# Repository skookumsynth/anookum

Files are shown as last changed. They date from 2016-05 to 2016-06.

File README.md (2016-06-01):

# Anookum

The Anookum is a derivative of Olivier Gillet's "Anushri" monophonic synthesizer.

https://github.com/pichenettes/anushri

It uses alternate parts to make sourcing easier for users in North America.
Files are licensed as per the original CC-BY-SA 3.0 license.

No warranties provided.
www.skookumsynth.com

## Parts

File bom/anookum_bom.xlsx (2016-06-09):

THIS BOM IS BASED ON THE ORIGINAL PROVIDED BY MUTABLE INSTRUMENTS. IT HAS BEEN MODIFIED. WHILE BEST EFFORTS HAVE BEEN MADE, COMPLETE ACCURACY CAN NOT BE GUARANTEED. IF ERRORS ARE NOTED, PLEASE NOTIFY CREATOR
DESIGNATOR | DESCRIPTION | QTY | DIGI-KEY | MOUSER | OTHER (CAVEAT EMPTOR)
RESISTORS
R1, R3, R4, R13 | 220 OHM 1/4W 1% | 4 | RNF14FTD221RCT-ND | 660-MF1/4DCT52R2200F | TAYDA | A-2246
R5, R6, R9, R10, R21, R22, R27, R51, R55, R57, R62 | 470 OHM 1/4W 1% | 11 | RNF14FTD470RCT-ND | 660-MF1/4DCT52R4700F | TAYDA | A-2247
R25, R38, R39, R45, R50, R52, R53 | 4K7 OHM 1/4W 1% | 7 | RNF14FTD4K75CT-ND | 660-MF1/4DCT52R4701F | TAYDA | A-2310
R2, R29, R37, R49, R63, R64, R70, R73, R77 | 10K OHM 1/4W 1% | 9 | RNF14FTD10K0CT-ND | 660-MF1/4DCT52R1002F | TAYDA | A-2203
R28 | 12K OHM 1/4W 1% | 1 | RNF14FTD12K1CT-ND | 660-MF1/4DCT52R1202F | TAYDA | A-2327
R18, R30, R35 | 15K OHM 1/4W 1% | 3 | RNF14FTD15K0CT-ND | 660-MF1/4DCT52R1502F | TAYDA | A-2182
R11, R14, R23, R26, R36, R40, R43, R44, R46, R47 | 22K OHM 1/4W 1% | 10 | RNF14FTD22K1CT-ND | 660-MF1/4DCT52R2202F | TAYDA | A-2284
R72 | 27K OHM 1/4W 1% | 1 | RNF14FTD27K4CT-ND | 660-MF1/4DCT52R2702F | TAYDA | A-2772
R12, R16, R17, R19, R20, R24, R31, R54, R67 | 33K OHM 1/4W 1% | 9 | RNF14FTD33K2CT-ND | 660-MF1/4DCT52R3302F | TAYDA | A-2290
R71 | 39K OHM 1/4W 1% | 1 | RNF14FTD39K2CT-ND | 660-MF1/4DCT52R3902F | TAYDA | A-2313
R68 | 49K9 OHM 1/4W 1% | 1 | RNF14FTD49K9CT-ND | 660-MF1/4DCT52R4992F | TAYDA
R66 | 62K OHM 1/4W 1% | 1 | RNF14FTD61K9CT-ND | 660-MF1/4DCT52R6192F | TAYDA | A-2628
R56, R59 | 68K OHM 1/4W 1% | 2 | RNF14FTD68K1CT-ND | 660-MF1/4DCT52R6812F | TAYDA | A-2334
R7, R8, R33, R34, R41, R42, R48, R60, R61 | 100K OHM 1/4W 1% | 9 | RNF14FTD100KCT-ND | 660-MF1/4DCT52R1003F | TAYDA | A-2248
R32 | 150K OHM 1/4W 1% | 1 | RNF14FTD150KCT-ND | 660-MF1/4DCT52R1503F | TAYDA | A-2210
R15, R58, R65, R69 | 200K OHM 1/4W 1% | 4 | RNF14FTD200KCT-ND | 660-MF1/4DCT52R2003F | TAYDA | A-2630
RN1 | ARRAY 6 RES 10K | 1 | 4607X-101-103LF-ND | 652-4607X-1LF-10K
R74, R75, R76 | TRIMMER 10K | 3 | 490-2875-ND | 652-3296W-1-103LF | TAYDA | A-586
RESISTORS - CONTROL BOARD
R6, R7, R13, R14, R15, R16 | 220 OHM 1/4W 1% | 6 | RNF14FTD221RCT-ND | 660-MF1/4DCT52R2200F | TAYDA | A-2246
CAPACITORS
C20, C51 | CER 10PF 50V NP0 RADIAL | 2 | BC1001CT-ND | 594-K100K15C0GF53L2
C54, C55 | CER 18PF 50V NP0 RADIAL | 2 | BC1004CT-ND | 594-K180J15C0GF5TL2
C12 | CER 100PF 50V NP0 RADIAL | 1 | BC1013CT-ND | 594-K101J15C0GF5TL2
C14, C28 | CER 220PF 50V NP0 RADIAL | 2 | BC1017CT-ND | 23PS122
C8, C17, C30, C32, C35 | CER 560PF 50V NP0 RADIAL | 5 | BC1022CT-ND | 594-K561J15C0GF5TL2
C9 | FILM 2.2N% 63VDC | 1 | 399-9692-1-ND | 23PS222 | TAYDA
C4 | FILM 22N 5% 63VDC | 1 | 399-5451-1-ND | 505-MKS2.022/63/5T | TAYDA
C1, C3, C10, C11, C13, C15, C16, C18, C19, C21, C22, C23, C24, C25, C26, C27, C29, C31, C33, C34, C36, C37, C39, C40, C41, C42, C43, C45, C46, C47, C48, C50, C53 | CER 0.1UF 25V Y5V RADIAL | 33 | BC1148CT-ND | 75-1C10Z5U104M050B | TAYDA | A-214
C2, C5, C6, C7 | ALUM 4.7UF 20% 35V RADIAL | 4 | 493-10854-1-ND | 647-UVP1E4R7MDD
C56 | TANT 10UF 25V 20% | 1 | 478-5813-ND | 581-TAP106K016SRW |  |  | NOT NEEDED IF USED W/ EURORACK PSU
C38, C44, C49, C52, C57 | ALUM 100UF 20% 25V RADIAL | 5 | P10269-ND | 140-SEA101M1CBK0607
SEMICONDUCTORS
D1, D5, D6 | DIODE, GP | 3 | 1N4148TACT-ND | 78-1N4148-TAP | TAYDA | A-157
D3, D4 | DIODE ZENER 3.6V 500MW | 2 | 1N5227B-ND | 512-1N5227B | TAYDA | A-165
D2, D7, D8 | DIODE GEN PURP 50V 1A | 3 | 641-1310-1-ND | 625-1N4001-E3/73 | TAYDA | A-162
Q1 | JFET N-CH 35V 625MW | 1 | J112_D26ZCT-ND | 610-2N5485 | TAYDA | A-908
Q2 | TRANS PNP 40V 0.2A | 1 | 2N3906-APCT-ND | 512-2N3906TA | TAYDA | A-117
Q3 | XTAL 20.0000MHZ 30PPM 20PF | 1 | 631-1111-ND | 717-9B-20.000MAAJ-B | TAYDA | A-236
INTEGRATED CIRCUITS
OK1 | OPTOISO 5KV OPEN COLLECTOR | 1 | 160-1791-ND | 782-6N137 | TAYDA | A-871
IC24 | REG SWTCHD CAP INV RATIO | 1 | 296-17596-5-ND | 595-LT1054CP | FUTURLEC |  | NOT NEEDED IF USED W/ EURORACK PSU
IC23 | MCU 8BIT 32KB FLASH | 1 | ATMEGA328P-PU-ND | 556-ATMEGA328P-PU | TAYDA | A-854
IC15 | BUFF/CONVERTER HEX | 1 | 296-2056-5-ND | 595-CD4050BE | TAYDA | A-906
IC11 | COUNTER/DIVIDER BINRY | 1 | 296-2042-5-ND | 595-CD4024BE | TAYDA | A-019
IC17, IC18 | MUX/DEMUX 8X1 | 2 | 296-2057-5-ND | 595-CD4051BE | TAYDA | A-495
IC22 | 8-BIT SHIFT REGISTER | 1 | 296-8251-5-ND | 595-SN74HC165N | TAYDA | A-639
IC16 | 8-BIT SHIFT REGISTER | 1 | 296-1600-5-ND | 595-SN74HC595N | TAYDA | A-024
IC3, IC7, IC9 | OPAMP, DUAL, GP | 3 | 296-14997-5-ND | 595-TL072CP | TAYDA | A-037
IC5, IC10 | OPAMP, QUAD, GP | 2 | 296-1777-5-ND | 595-TL074CN | TAYDA | A-1138
IC2 | OPAMP GP 3MHZ RRO | 1 | 296-12219-5-ND | 595-TLV2372IP | N/A
IC8 | DIFF COMP W/STROBE | 1 | 296-1389-5-ND | 595-LM311P | TAYDA | A-204
IC6 | VCA, EXP, QUAD | 1 | N/A | N/A | CABINTECH, SMALLBEAR
IC4 | OTA, DUAL W/ BUFF | 1 | LM13700N/NOPB-ND | 926-LM13700N/NOPB | TAYDA | A-900
IC19, IC20 | DAC 12BIT DUAL W/SPI | 2 | MCP4822-E/P-ND | 579-MCP4822-E/P | FUTURLEC
IC1, IC12, IC13 | VREF SHUNT 4.096V | 3 | LM4040AIZ-4.1/NOPB-ND | 926-LM4040AIZ4.1NOPB
IC14 | REG LDO 5V 1A | 1 | LM7805CT | 863-MC7805ACTG | TAYDA | A-179
IC21 | REG LDO -5V 1A | 1 | LM7905CTFS-ND | 863-MC7905ACTG | TAYDA | A-258
SWITCHES, CONNECTORS OPTIONAL
S1 | SWITCH SLIDE SPDT 100MA 12V | 1 | CKN9559-ND | OS102011MA1QN1 |  |  | NOT NEEDED IF USED W/ EURORACK PSU
X1, X2 | CONN DIN 5 PIN FEMALE PCB | 2 | CP-2350-ND | 490-SDS-50J |  |  | NOT NEEDED IF USED IN EURORACK
J2, J3 | 1/4" PHONO JACK MONO | 2 | N/A | 550-10284 |  |  | NOT NEEDED IF USED IN EURORACK
J1 | CONN POWER JACK 2.1MM | 1 | CP-202A-ND | 163-7620E-E |  |  | NOT NEEDED IF USED W/ EURORACK PSU
SOCKETS
 | CONN IC DIP SOCKET 8POS TIN | 9 | ED3044-5-ND | 571-1-390261-2 | TAYDA | A-001
 | CONN IC DIP SOCKET 14POS TIN | 3 | ED3045-5-ND | 571-1-390261-3 | TAYDA | A-004
 | CONN IC DIP SOCKET 16POS TIN | 7 | ED3046-5-ND | 571-1-390261-4 | TAYDA | A-003
 | CONN IC DIP SOCKET 28POS TIN | 1 | ED3050-5-ND | 571-1-390261-9 | TAYDA | A-1601
SWITCHES
SW1, SW2, SW3, SW4, SW5 | SWITCH TACT SPST | 5 | 401-1978-ND | 611-D6R90LFS | FUTURLEC | TACT008 | E-SWITCH "KS" SERIES POSSIBLE ALTERNATIVE
SW6 | SWITCH TACT SPST | 1 | 401-1975-ND | 611-D6R40F1LFS | FUTURLEC | TACT009 | E-SWITCH "KS" SERIES POSSIBLE ALTERNATIVE
SW7, SW8 | SWITCH TOGGLE SP3T | 2 | 100DP6T1B1M1RE-ND | 612-100-L1111 |  |  | TAYDAS DPDT DOES NOT WORK
SW9, SW10 | SWITCH TOGGLE SPDT | 2 | EG2351-ND | 612-100-A1111 | TAYDA
CONNECTORS/JACKS
ISP | CONN HEADER VERT DUAL 6POS GOLD | 1 | 3M9459-ND | 649-67996-406HLF | TAYDA | A-638 | 2 x TAYDA OPTION SUFF. FOR ALL M HEADERS
J4, J5, J6, J7 | CONN HEADER VERT DUAL 16POS GOLD | 4 | 3M9461-ND | 649-67996-416HLF
JP1 | CONN HEADER VERT DUAL 10POS GOLD | 1 | 1175-1609-ND | 571-5103308-1 | FUTURLEC | IDCMH10
J5, J14, J15, J16 | CONN HEADER 16 POS | 4 | S7076-ND | 649-76342-308LF | FUTURLEC | FHEADD16
J1, J2, J3, J4, J6 .. J13 | 3.5MM JACKS, VERTICAL, "THONKICONN" | 12 | N/A | N/A | ERTHENVAR, THONK
LEDS
LED1 .. LED6 | LED YELLOW DIFF 3MM ROUND | 6 | 754-1306-ND | 604-WP424YDT | TAYDA | A-263
POTENTIOMETERS
R1, R2, R3, R4, R5, R8, R9, R10, R11, R12, R19, R20, R21, R22, R24, R25 | POT 9MM 10KB FLATTED | 16 | N/A | 688-RK09D1130C2P
R26, R27 | POT 9MM 100KA FLATTED | 2 | N/A | 688-RK09D113F25C0A
R17, R18, R23 | POT 9MM 10KB DETENT FLATTED | 3 | N/A | 688-RK09D1130C3C
KNOBS
KNOBS | KNOB BLACK | 21 | N/A | N/A
CAP | CAP, BLACK | 7 | N/A | N/A
CAP | CAP, GRAY | 10 | N/A | N/A
CAP | CAP, BLUE | 3 | N/A | N/A
CAP | CAP, RED | 1 | N/A | N/A
PCBS
MAIN PCB | MAIN PCB | 1 | N/A | N/A
CONTROL PCB | CONTROL PCB | 1 | N/A | N/A
HARDWARE
STANDOFFS | HEX STANDOFF M3 ALUMINUM 10MM M-F | 4 | 36-24313-ND | 534-24313 | GENERIC, EBAY
STANDOFFS | HEX STANDOFF M3 ALUMINUM 12MM F-F | 10 | 36-24394-ND | 534-24394 | GENERIC, EBAY
SCREWS | MACHINE SCREW PAN PHILLIPS M3 | 20 | 335-1156-ND | 534-9191-4 | GENERIC, EBAY

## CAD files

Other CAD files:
panel/anookum_panel_ACAD2K.dwg

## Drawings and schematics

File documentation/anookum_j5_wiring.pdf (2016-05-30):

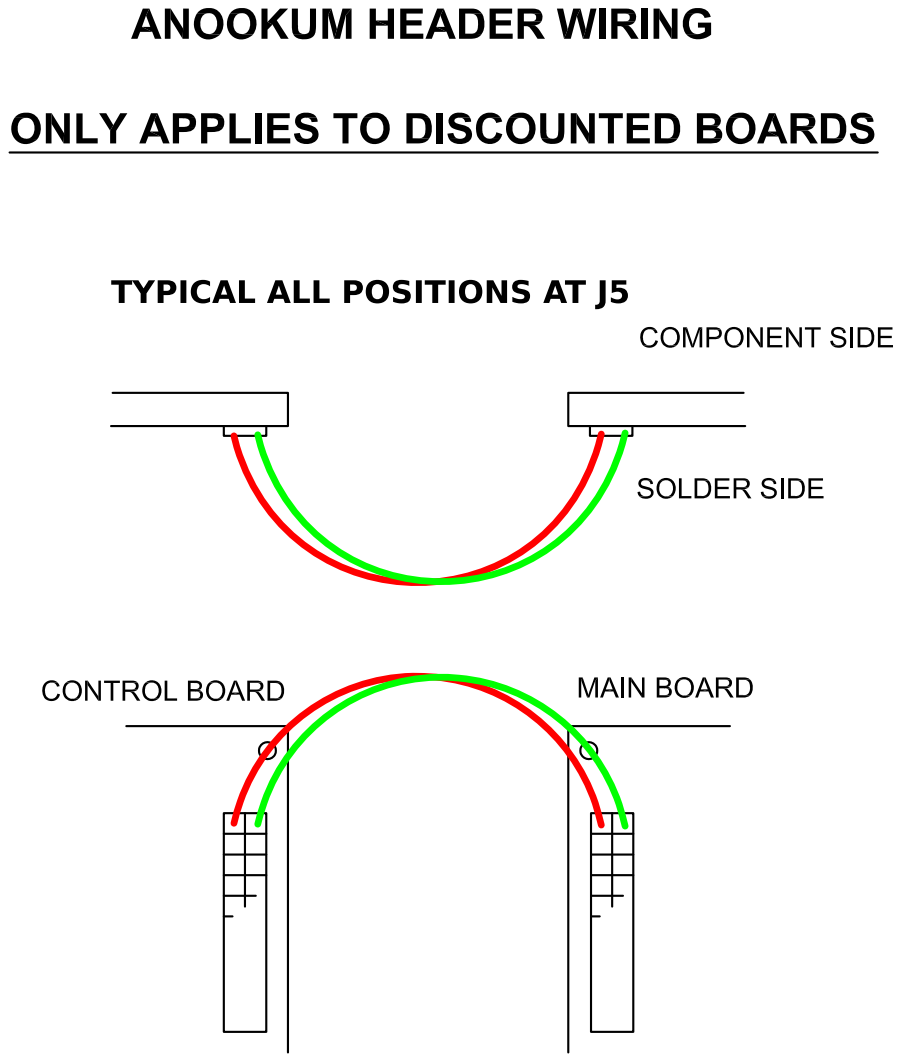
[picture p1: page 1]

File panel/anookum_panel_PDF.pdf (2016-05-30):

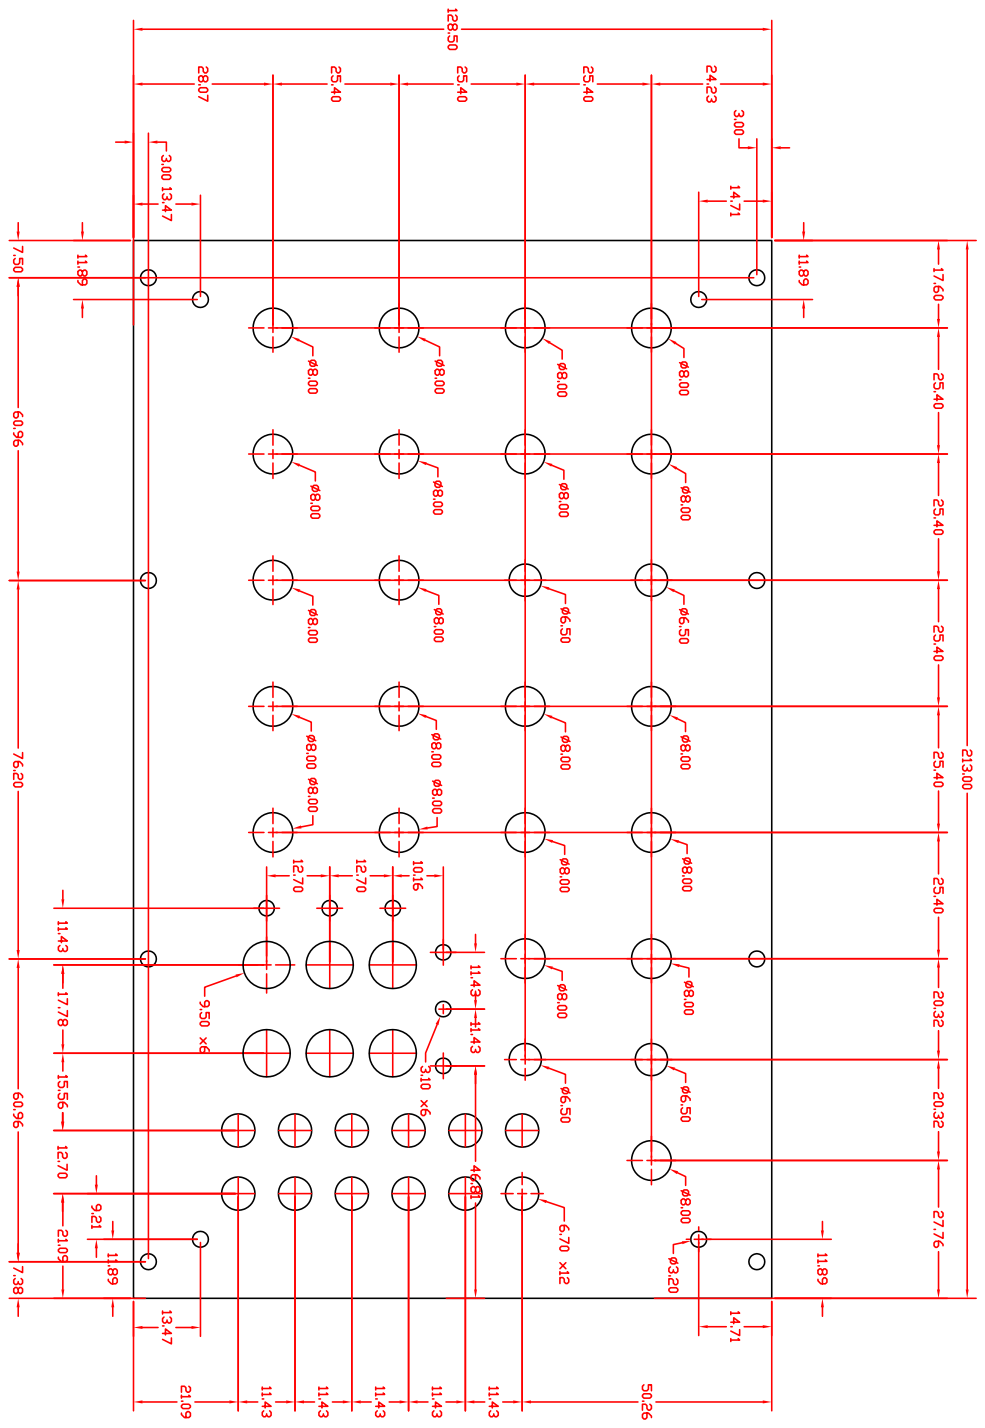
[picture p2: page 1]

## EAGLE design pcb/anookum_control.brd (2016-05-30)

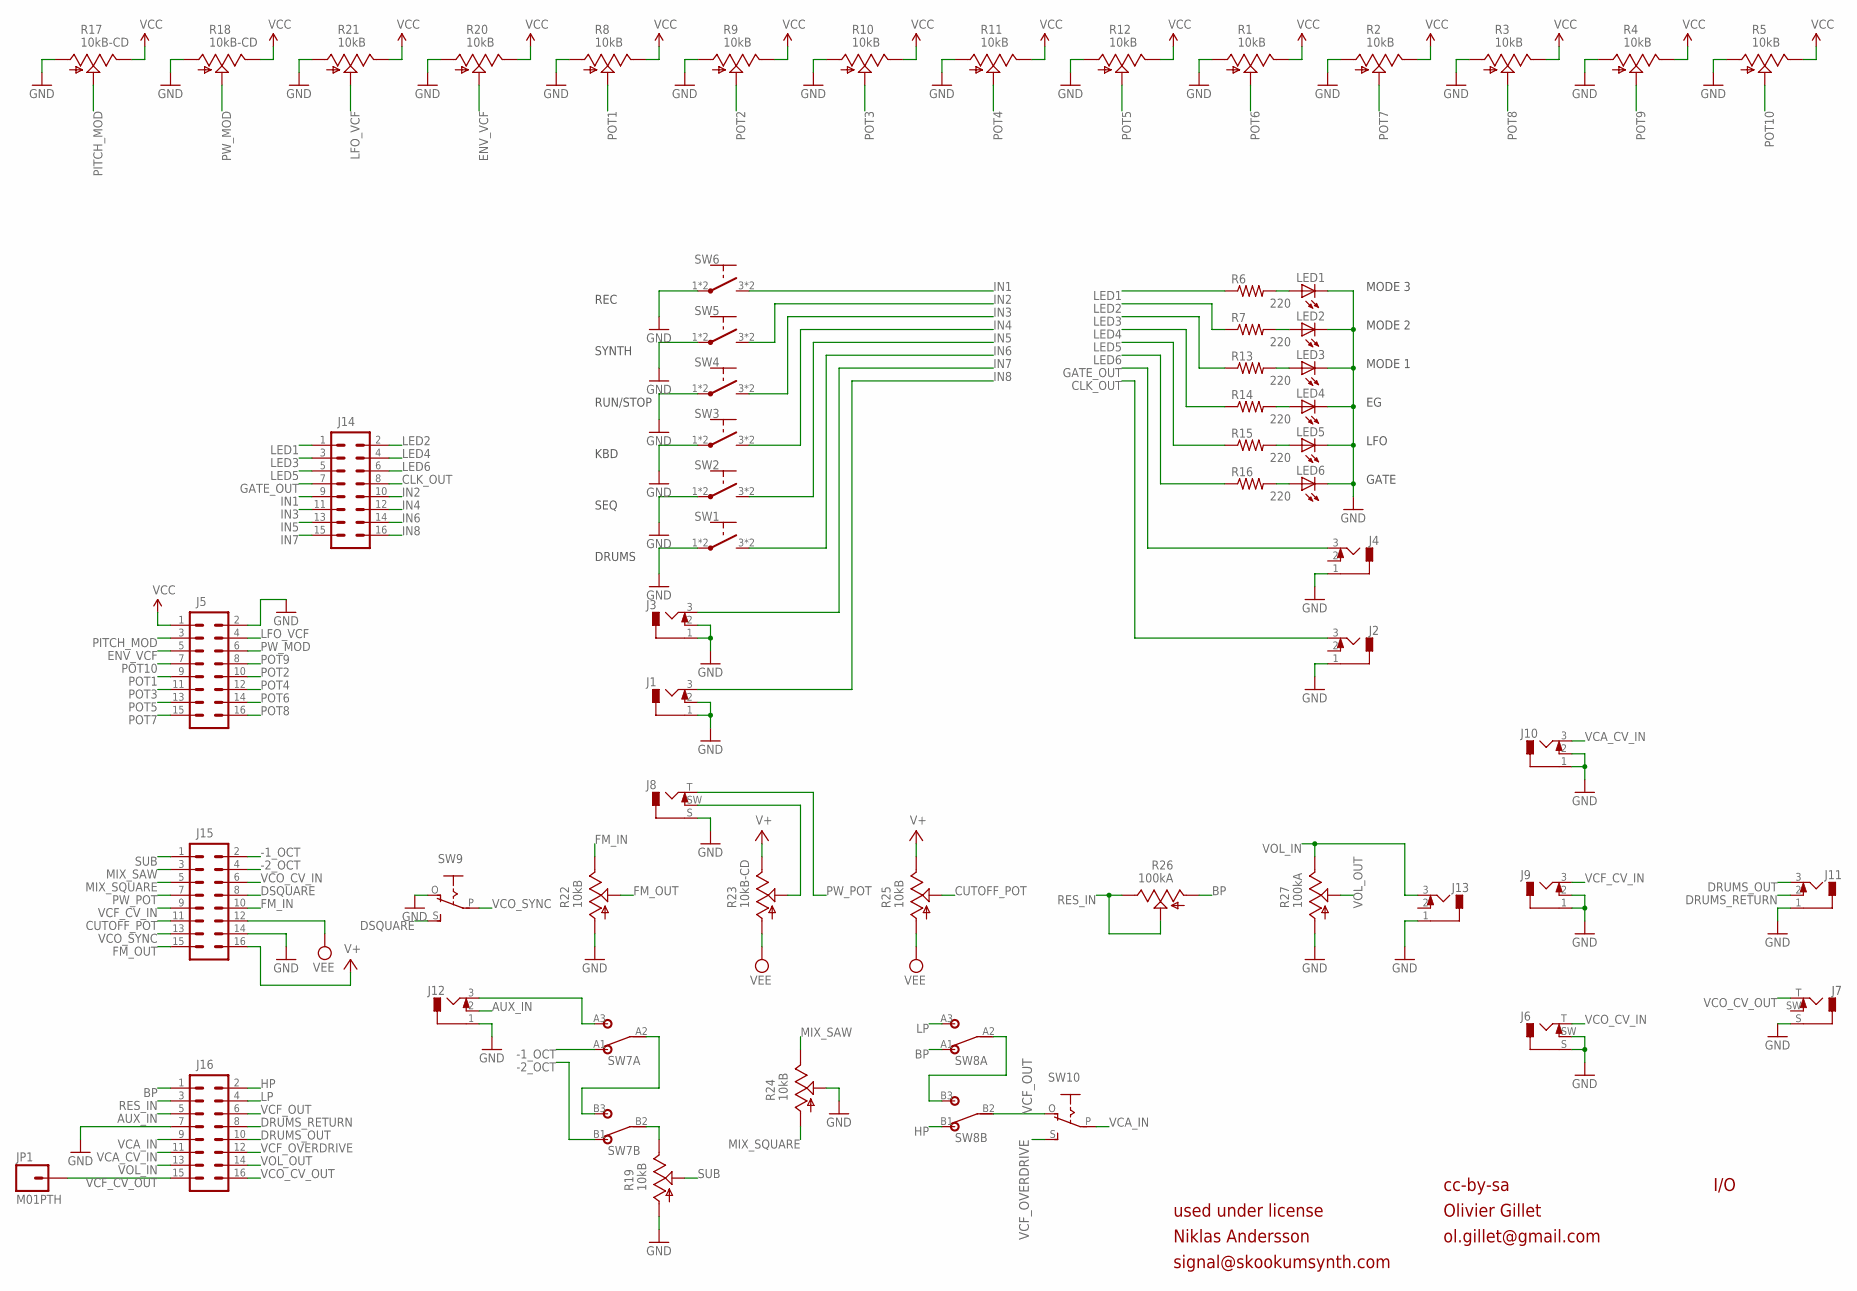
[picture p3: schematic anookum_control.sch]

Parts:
J1, J2, J3, J4, J9, J10, J11, J12, J13: JACK_MONO_SW_V; WQP_PJ301M-12@1
J5, J14, J15, J16: M08X2; 2X8
J6, J7, J8: CONN_MONO_SW_F_V; WQP_PJ301M-12
JP1: M01PTH; 1X01
LED1, LED2, LED3, LED4, LED5, LED6: LED3MM
R1, R2, R3, R4, R5, R8, R9, R10, R11, R12, R19, R20, R21, R22, R24, R25: 10kB; ALPS_POT_VERTICAL
R6, R7, R13, R14, R15, R16: 220; 0204/7
R17, R18, R23: 10kB-CD; ALPS_POT_VERTICAL
R26, R27: 100kA; ALPS_POT_VERTICAL
SW1, SW2, SW3, SW4, SW5, SW6: SW_TACTD6; D6
SW7, SW8: DPDT1AD6T2B4M2RE; DPDT
SW9, SW10: EG1218S; EG1218

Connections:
-1_OCT: J15.2, SW7.A1 (1)
-2_OCT: J15.4, SW7.B1 (1)
AUX_IN: J12.2 (SW), J16.5
BP: J16.1, R26.P$3 (A), SW8.A1 (1)
CLK_OUT: J2.3 (T), J14.8
CUTOFF_POT: J15.11, R25.P$2 (S)
DRUMS_OUT: J11.3 (T), J16.10
DRUMS_RETURN: J11.2 (SW), J16.8
DSQUARE: J15.8, SW9.S
ENV_VCF: J5.5, R20.P$2 (S)
FM_IN: J15.10, R22.P$1 (E)
FM_OUT: J15.15, R22.P$2 (S)
GATE_OUT: J4.3 (T), J14.7
GND: J1.1 (S), J1.2 (SW), J2.1 (S), J3.1 (S), J3.2 (SW), J4.1 (S), J5.2, J6.S, J6.SW, J7.S, J8.S, J9.1 (S), J9.2 (SW), J10.1 (S), J10.2 (SW), J11.1 (S), J12.1 (S), J13.1 (S), J15.14, J16.7, LED1.K (C), LED2.K (C), LED3.K (C), LED4.K (C), LED5.K (C), LED6.K (C), R1.P$3 (A), R2.P$3 (A), R3.P$3 (A), R4.P$3 (A), R5.P$3 (A), R8.P$3 (A), R9.P$3 (A), R10.P$3 (A), R11.P$3 (A), R12.P$3 (A), R17.P$3 (A), R18.P$3 (A), R19.P$3 (A), R20.P$3 (A), R21.P$3 (A), R22.P$3 (A), R24.P$2 (S), R27.P$3 (A), SW1.1, SW1.2 (1), SW2.1, SW2.2 (1), SW3.1, SW3.2 (1), SW4.1, SW4.2 (1), SW5.1, SW5.2 (1), SW6.1, SW6.2 (1), SW9.O
HP: J16.2, SW8.B1 (1)
IN1: J14.9, SW6.3 (2), SW6.4 (2)
IN2: J14.10, SW5.3 (2), SW5.4 (2)
IN3: J14.11, SW4.3 (2), SW4.4 (2)
IN4: J14.12, SW3.3 (2), SW3.4 (2)
IN5: J14.13, SW2.3 (2), SW2.4 (2)
IN6: J14.14, SW1.3 (2), SW1.4 (2)
IN7: J3.3 (T), J14.15
IN8: J1.3 (T), J14.16
LED1: J14.1, R6.1
LED2: J14.2, R7.1
LED3: J14.3, R13.1
LED4: J14.4, R14.1
LED5: J14.5, R15.1
LED6: J14.6, R16.1
LFO_VCF: J5.4, R21.P$2 (S)
LP: J16.4, SW8.A3 (3)
MIX_SAW: J15.3, R24.P$1 (E)
MIX_SQUARE: J15.5, R24.P$3 (A)
unnamed: J8.SW, R23.P$2 (S)
unnamed: R19.P$1 (E), SW7.B2 (2)
unnamed: J12.3 (T), SW7.A3 (3)
unnamed: SW8.A2 (2), SW8.B3 (3)
unnamed: LED1.A, R6.2
unnamed: LED2.A, R7.2
unnamed: LED3.A, R13.2
unnamed: LED4.A, R14.2
unnamed: LED5.A, R15.2
unnamed: LED6.A, R16.2
unnamed: SW7.A2 (2), SW7.B3 (3)
PITCH_MOD: J5.3, R17.P$2 (S)
POT1: J5.9, R8.P$2 (S)
POT2: J5.10, R9.P$2 (S)
POT3: J5.11, R10.P$2 (S)
POT4: J5.12, R11.P$2 (S)
POT5: J5.13, R12.P$2 (S)
POT6: J5.14, R1.P$2 (S)
POT7: J5.15, R2.P$2 (S)
POT8: J5.16, R3.P$2 (S)
POT9: J5.8, R4.P$2 (S)
POT10: J5.7, R5.P$2 (S)
PW_MOD: J5.6, R18.P$2 (S)
PW_POT: J8.T, J15.7
RES_IN: J16.3, R26.P$1 (E), R26.P$2 (S)
SUB: J15.1, R19.P$2 (S)
V+: J15.16, R23.P$1 (E), R25.P$1 (E)
VCA_CV_IN: J10.3 (T), J16.11
VCA_IN: J16.9, SW10.P
VCC: J5.1, R1.P$1 (E), R2.P$1 (E), R3.P$1 (E), R4.P$1 (E), R5.P$1 (E), R8.P$1 (E), R9.P$1 (E), R10.P$1 (E), R11.P$1 (E), R12.P$1 (E), R17.P$1 (E), R18.P$1 (E), R20.P$1 (E), R21.P$1 (E)
VCF_CV_IN: J9.3 (T), J15.9
VCF_CV_OUT: J16.15, JP1.1
VCF_OUT: J16.6, SW8.B2 (2), SW10.O
VCF_OVERDRIVE: J16.12, SW10.S
VCO_CV_IN: J6.T, J15.6
VCO_CV_OUT: J7.T, J16.16
VCO_SYNC: J15.13, SW9.P
VEE: J15.12, R23.P$3 (A), R25.P$3 (A)
VOL_IN: J13.3 (T), J16.13, R27.P$1 (E)
VOL_OUT: J16.14, R27.P$2 (S)

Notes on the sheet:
LFO
GATE
MODE 1
MODE 2
MODE 3
cc-by-sa
Olivier Gillet
ol.gillet@gmail.com
I/O
KBD
SEQ
SYNTH
RUN/STOP
REC
DRUMS
used under license
Niklas Andersson
signal@skookumsynth.com

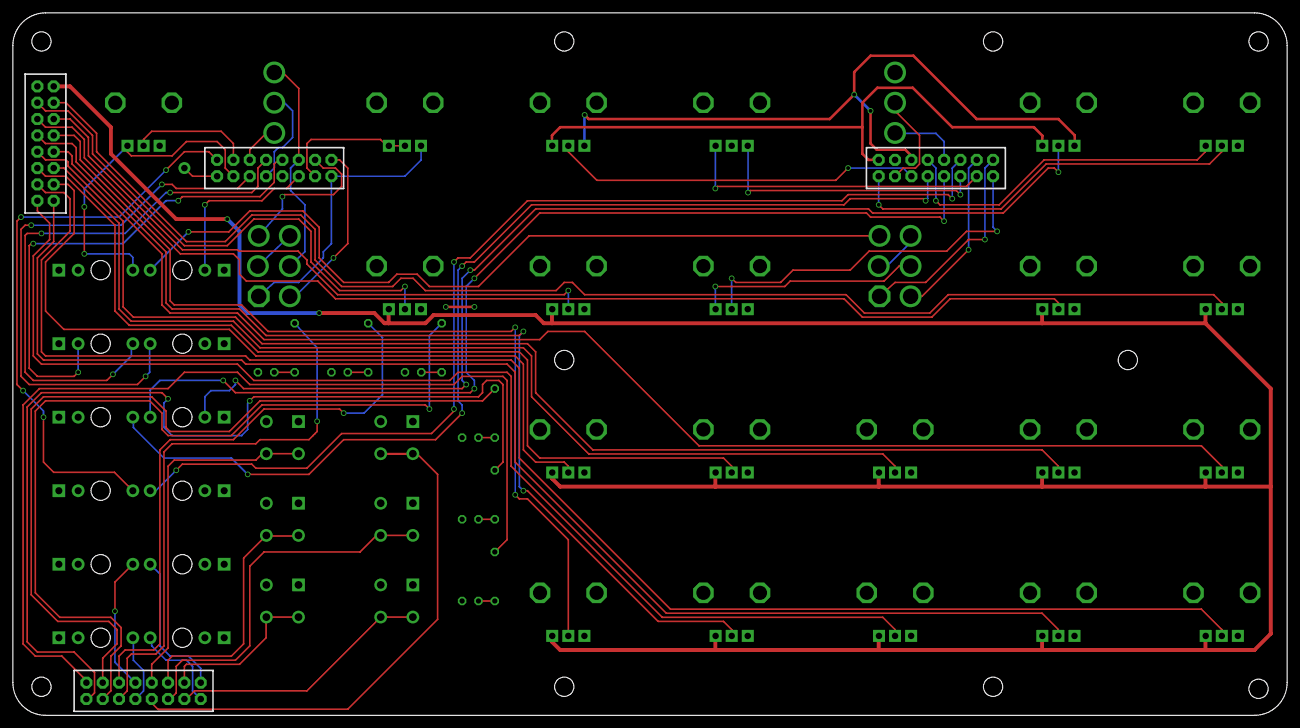
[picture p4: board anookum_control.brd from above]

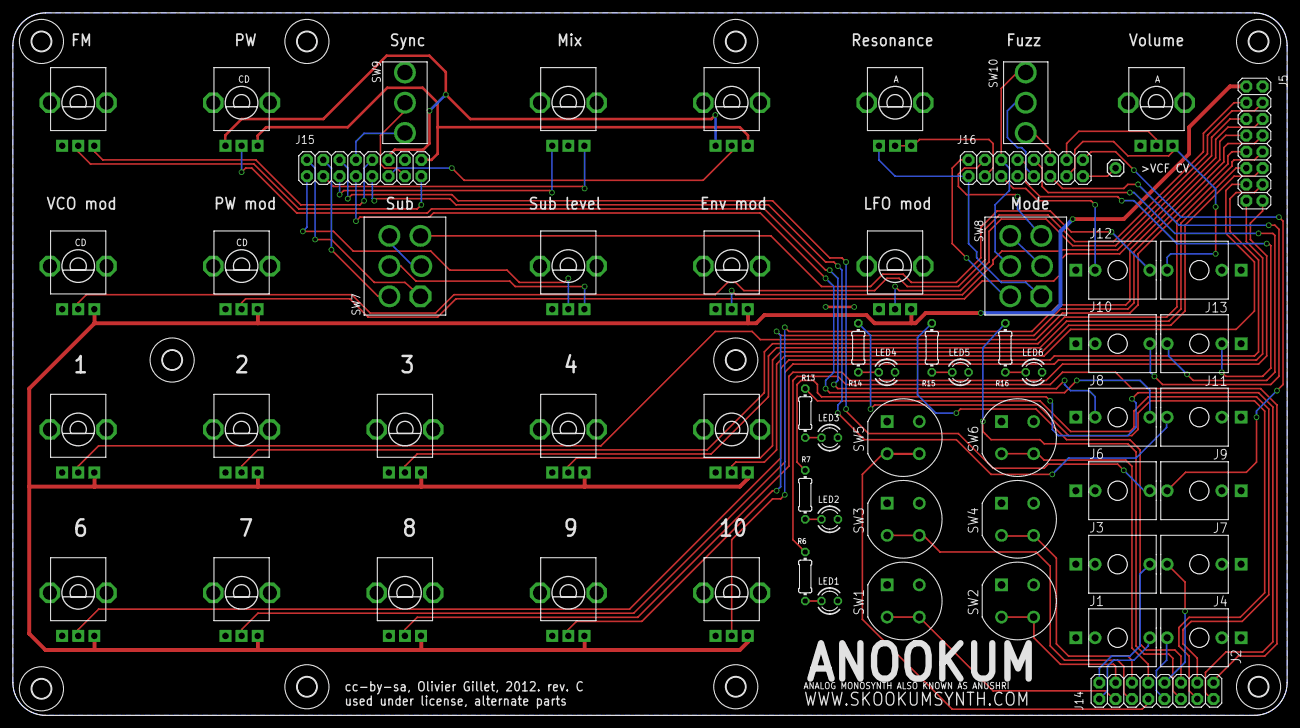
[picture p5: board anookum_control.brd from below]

Board: 2 copper layers, 198.1 x 109.2 mm, 70 parts (70 on the bottom side), 73 nets.

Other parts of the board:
U$1, U$2, U$3, U$4, U$6, U$7, U$8, U$9, U$10, U$11: 3,0

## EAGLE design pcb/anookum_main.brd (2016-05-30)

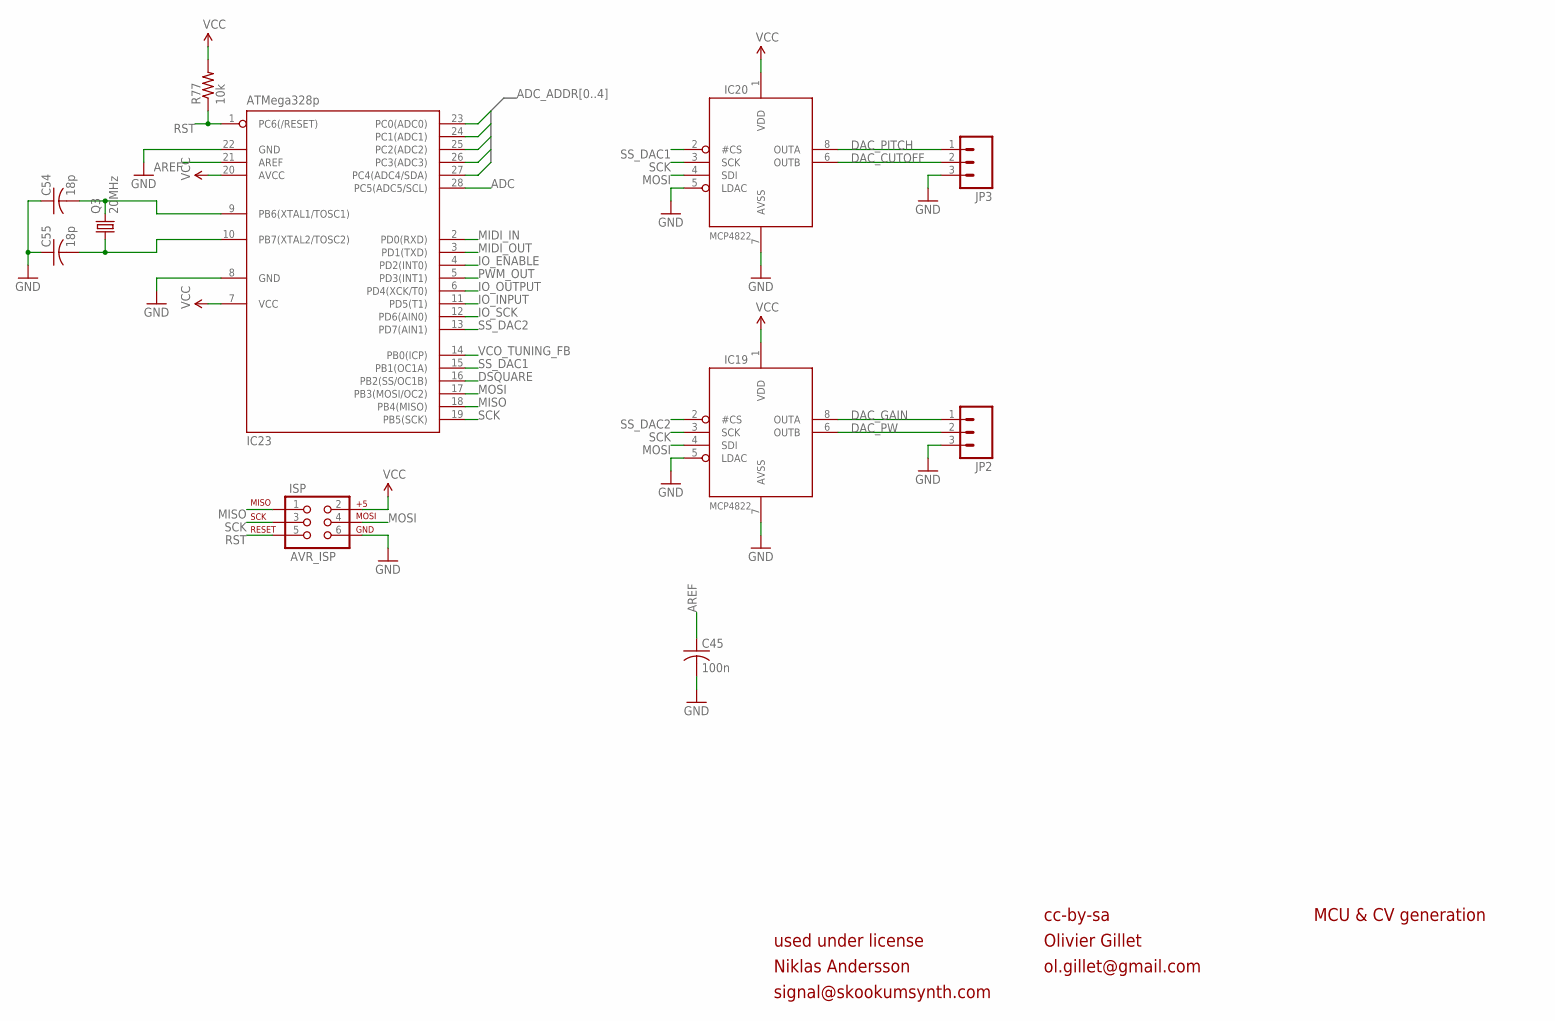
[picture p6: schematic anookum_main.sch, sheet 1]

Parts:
C45: 100n; C025-025X050
C54, C55: 18p; C025-025X050
IC19, IC20: MCP4822; DIL08
IC23: ATMega328p; DIL28-3
ISP: AVR_ISP; 2X3
JP2, JP3: M03PTH; 1X03
Q3: 20MHz; HC49U-V
R77: 10k; 0204/7

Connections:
ADC: IC23.28 (PC5(ADC5/SCL)); also elsewhere on the board
ADC_ADDR0: IC23.25 (PC2(ADC2)); also elsewhere on the board
ADC_ADDR1: IC23.24 (PC1(ADC1)); also elsewhere on the board
ADC_ADDR2: IC23.23 (PC0(ADC0)); also elsewhere on the board
ADC_ADDR3: IC23.26 (PC3(ADC3)); also elsewhere on the board
ADC_ADDR4: IC23.27 (PC4(ADC4/SDA)); also elsewhere on the board
AREF: C45.1, IC23.21 (AREF)
DAC_CUTOFF: IC20.6 (OUTB), JP3.2; also elsewhere on the board
DAC_GAIN: IC19.8 (OUTA), JP2.1; also elsewhere on the board
DAC_PITCH: IC20.8 (OUTA), JP3.1; also elsewhere on the board
DAC_PW: IC19.6 (OUTB), JP2.2; also elsewhere on the board
DSQUARE: IC23.16 (PB2(SS/OC1B)); also elsewhere on the board
GND: C45.2, C54.1, C55.1, IC19.5 (LDAC), IC19.7 (AVSS), IC20.5 (LDAC), IC20.7 (AVSS), IC23.8 (GND), IC23.22 (GND), ISP.6, JP2.3, JP3.3; also elsewhere on the board
IO_ENABLE: IC23.4 (PD2(INT0)); also elsewhere on the board
IO_INPUT: IC23.11 (PD5(T1)); also elsewhere on the board
IO_OUTPUT: IC23.6 (PD4(XCK/T0)); also elsewhere on the board
IO_SCK: IC23.12 (PD6(AIN0)); also elsewhere on the board
MIDI_IN: IC23.2 (PD0(RXD)); also elsewhere on the board
MIDI_OUT: IC23.3 (PD1(TXD)); also elsewhere on the board
MISO: IC23.18 (PB4(MISO)), ISP.1
MOSI: IC19.4 (SDI), IC20.4 (SDI), IC23.17 (PB3(MOSI/OC2)), ISP.4
unnamed: C55.2, IC23.10 (PB7(XTAL2/TOSC2)), Q3.1
unnamed: C54.2, IC23.9 (PB6(XTAL1/TOSC1)), Q3.2
PWM_OUT: IC23.5 (PD3(INT1)); also elsewhere on the board
RST: IC23.1 (PC6(/RESET)), ISP.5, R77.1
SCK: IC19.3 (SCK), IC20.3 (SCK), IC23.19 (PB5(SCK)), ISP.3
SS_DAC1: IC20.2 (#CS), IC23.15 (PB1(OC1A))
SS_DAC2: IC19.2 (#CS), IC23.13 (PD7(AIN1))
VCC: IC19.1 (VDD), IC20.1 (VDD), IC23.7 (VCC), IC23.20 (AVCC), ISP.2, R77.2; also elsewhere on the board
VCO_TUNING_FB: IC23.14 (PB0(ICP)); also elsewhere on the board

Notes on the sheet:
cc-by-sa
Olivier Gillet
ol.gillet@gmail.com
MCU & CV generation
used under license
Niklas Andersson
signal@skookumsynth.com

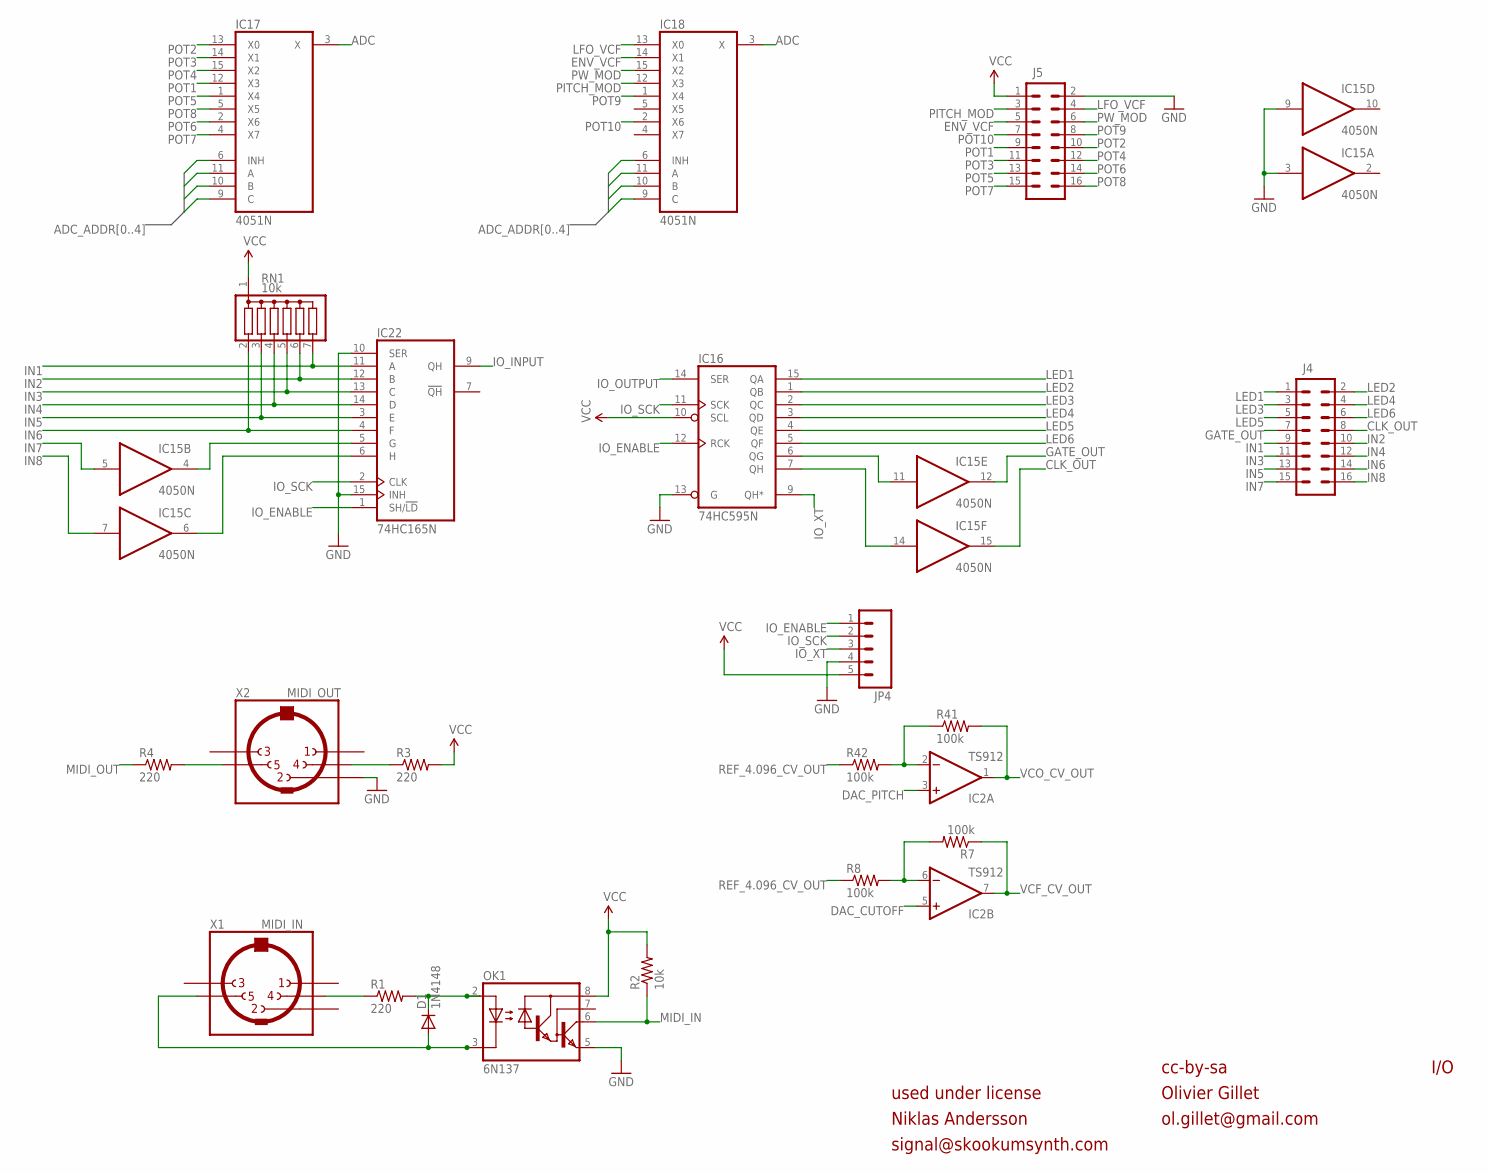
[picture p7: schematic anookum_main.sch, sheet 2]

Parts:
D1: 1N4148; D-5
IC2: TS912; DIL08
IC15: 4050N; DIL16
IC16: 74HC595N; DIL16
IC17, IC18: 4051N; DIL16
IC22: 74HC165N; DIL16
J4, J5: M08X2; 2X8
JP4: M05PTH; 1X05
OK1: 6N137; DIL08
R1, R3, R4: 220; 0204/7
R2: 10k; 0204/7
R7, R8, R41, R42: 100k; 0204/7
RN1: 10k; SIL7
X1: MIDI_IN; SDS-50J
X2: MIDI_OUT; SDS-50J

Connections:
ADC: IC17.3 (X), IC18.3 (X); also elsewhere on the board
ADC_ADDR0: IC17.11 (A), IC18.11 (A); also elsewhere on the board
ADC_ADDR1: IC17.10 (B), IC18.10 (B); also elsewhere on the board
ADC_ADDR2: IC17.9 (C), IC18.9 (C); also elsewhere on the board
ADC_ADDR3: IC17.6 (INH); also elsewhere on the board
ADC_ADDR4: IC18.6 (INH); also elsewhere on the board
CLK_OUT: IC15.15 (O), J4.8
DAC_CUTOFF: IC2.5 (+IN); also elsewhere on the board
DAC_PITCH: IC2.3 (+IN); also elsewhere on the board
ENV_VCF: IC18.14 (X1), J5.5
GATE_OUT: IC15.12 (O), J4.7
GND: IC15.3 (I), IC15.9 (I), IC16.13 (G), IC22.10 (SER), IC22.15 (INH), J5.2, JP4.4, OK1.5 (GND), X2.2; also elsewhere on the board
IN1: IC22.11 (A), J4.9, RN1.7
IN2: IC22.12 (B), J4.10, RN1.6
IN3: IC22.13 (C), J4.11, RN1.5
IN4: IC22.14 (D), J4.12, RN1.4
IN5: IC22.3 (E), J4.13, RN1.3
IN6: IC22.4 (F), J4.14, RN1.2
IN7: IC15.5 (I), J4.15
IN8: IC15.7 (I), J4.16
IO_ENABLE: IC16.12 (RCK), IC22.1 (SH/!LD), JP4.1; also elsewhere on the board
IO_INPUT: IC22.9 (QH); also elsewhere on the board
IO_OUTPUT: IC16.14 (SER); also elsewhere on the board
IO_SCK: IC16.11 (SCK), IC22.2 (CLK), JP4.2; also elsewhere on the board
IO_XT: IC16.9 (QH*), JP4.3
LED1: IC16.15 (QA), J4.1
LED2: IC16.1 (QB), J4.2
LED3: IC16.2 (QC), J4.3
LED4: IC16.3 (QD), J4.4
LED5: IC16.4 (QE), J4.5
LED6: IC16.5 (QF), J4.6
LFO_VCF: IC18.13 (X0), J5.4
MIDI_IN: OK1.6 (VO), R2.1; also elsewhere on the board
MIDI_IN4: R1.1, X1.4
MIDI_IN5: D1.A, OK1.3 (C), X1.5
MIDI_OUT: R4.1; also elsewhere on the board
MIDI_OUT3: R3.1, X2.4
MIDI_OUT5: R4.2, X2.5
unnamed: IC15.11 (I), IC16.6 (QG)
unnamed: IC15.14 (I), IC16.7 (QH)
unnamed: D1.C, OK1.2 (A), R1.2
unnamed: IC15.4 (O), IC22.5 (G)
unnamed: IC15.6 (O), IC22.6 (H)
unnamed: IC2.2 (-IN), R41.1, R42.2
unnamed: IC2.6 (-IN), R7.2, R8.2
PITCH_MOD: IC18.12 (X3), J5.3
POT1: IC17.12 (X3), J5.9
POT2: IC17.13 (X0), J5.10
POT3: IC17.14 (X1), J5.11
POT4: IC17.15 (X2), J5.12
POT5: IC17.1 (X4), J5.13
POT6: IC17.2 (X6), J5.14
POT7: IC17.4 (X7), J5.15
POT8: IC17.5 (X5), J5.16
POT9: IC18.1 (X4), J5.8
POT10: IC18.2 (X6), J5.7
PW_MOD: IC18.15 (X2), J5.6
REF_4.096_CV_OUT: R8.1, R42.1; also elsewhere on the board
VCC: IC16.10 (SCL), J5.1, JP4.5, OK1.8 (VCC), R2.2, R3.2, RN1.1; also elsewhere on the board
VCF_CV_OUT: IC2.7 (OUT), R7.1; also elsewhere on the board
VCO_CV_OUT: IC2.1 (OUT), R41.2; also elsewhere on the board

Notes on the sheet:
cc-by-sa
Olivier Gillet
ol.gillet@gmail.com
I/O
used under license
Niklas Andersson
signal@skookumsynth.com

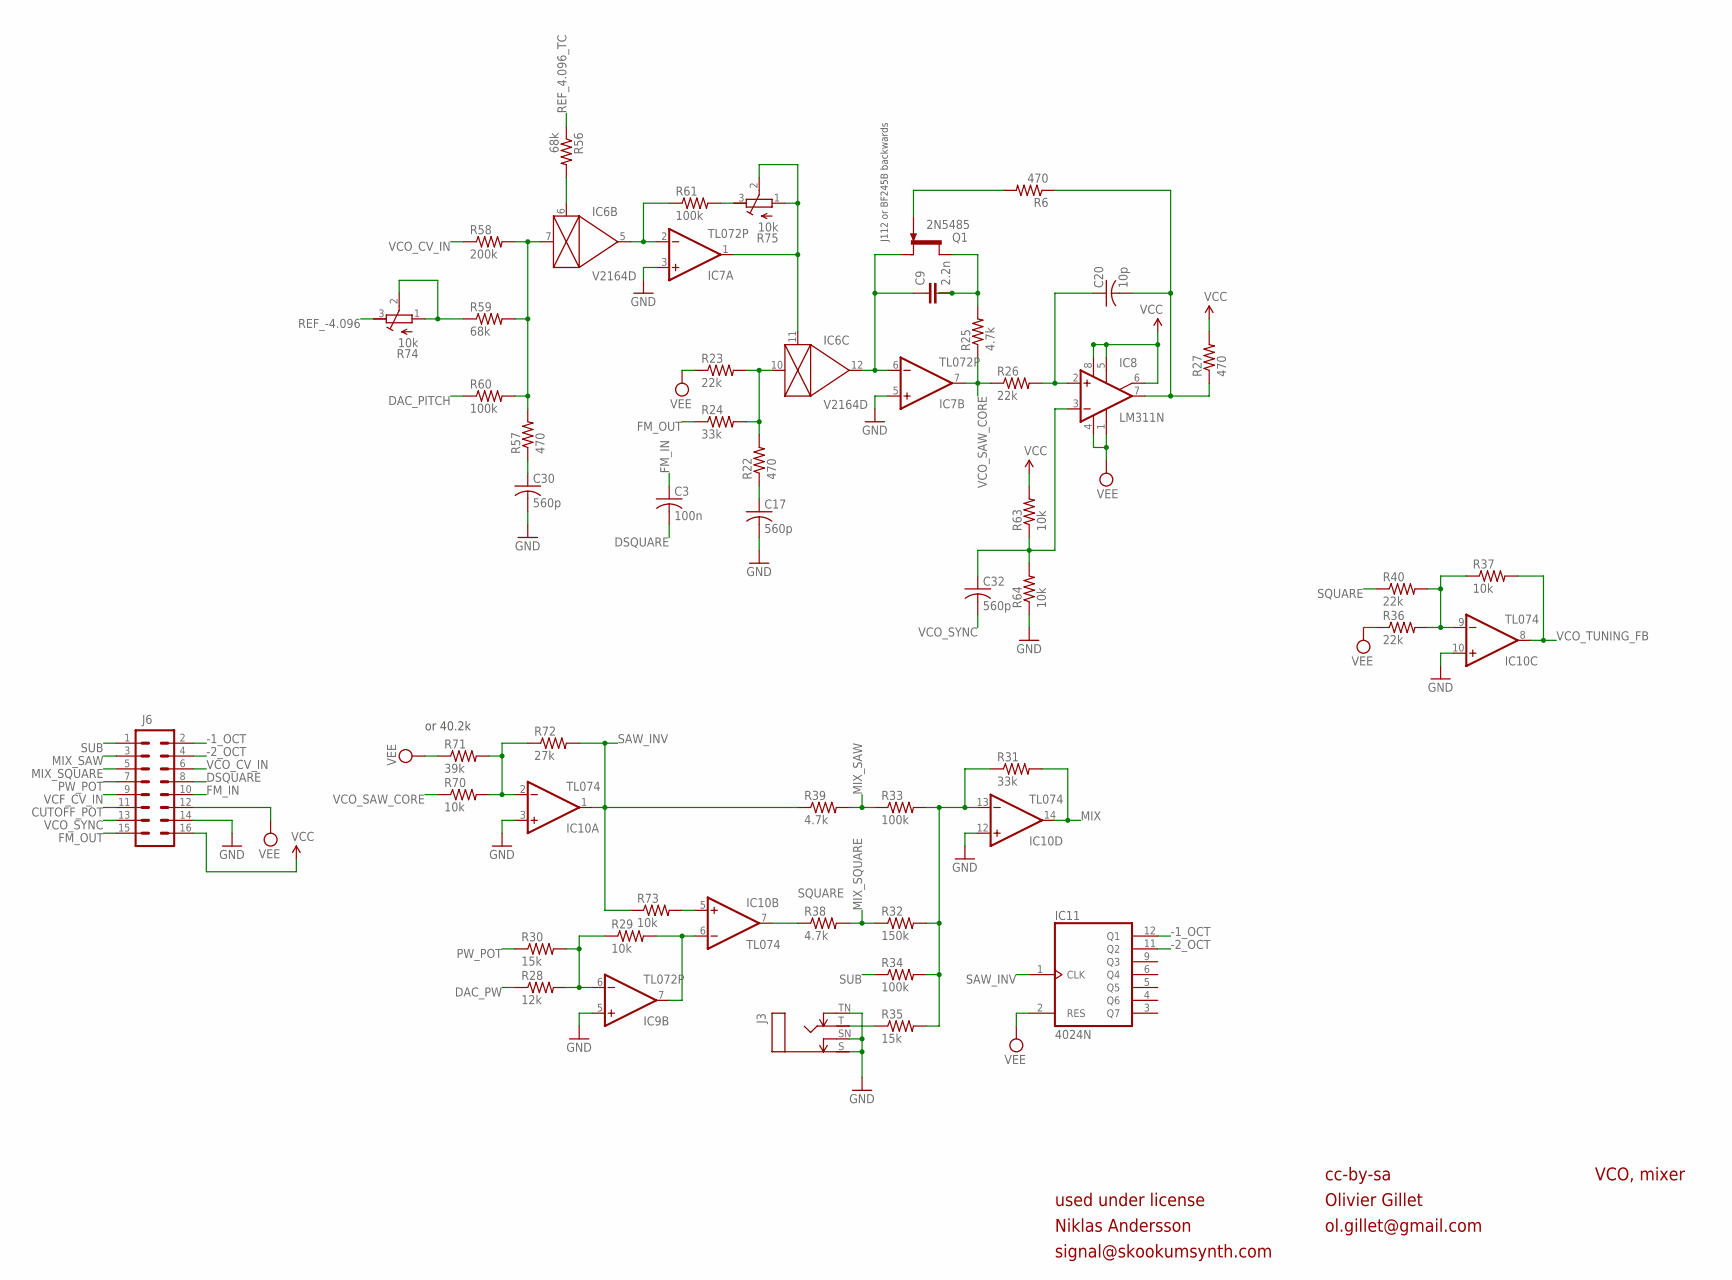
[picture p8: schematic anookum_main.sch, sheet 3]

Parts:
C3: 100n; C025-025X050
C9: 2.2n; C2.5/5-5
C17, C30, C32: 560p; C025-025X050
C20: 10p; C025-025X050
IC6: V2164D; DIL16
IC7, IC9: TL072P; DIL08
IC8: LM311N; DIL08
IC10: TL074; DIL14
IC11: 4024N; DIL14
J3: MONOSWSLIM; NRJ4HF
J6: M08X2; 2X8
Q1: 2N5485; TO92-
R6, R22, R27, R57: 470; 0204/7
R23, R26, R36, R40: 22k; 0204/7
R24, R31: 33k; 0204/7
R25, R38, R39: 4.7k; 0204/7
R28: 12k; 0204/7
R29, R37, R63, R64, R70, R73: 10k; 0204/7
R30, R35: 15k; 0204/7
R32: 150k; 0204/7
R33, R34, R60, R61: 100k; 0204/7
R56, R59: 68k; 0204/7
R58: 200k; 0204/7
R71: 39k; 0204/7
R72: 27k; 0204/7
R74, R75: 10k; RTRIM3296W

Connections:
-1_OCT: IC11.12 (Q1), J6.2
-2_OCT: IC11.11 (Q2), J6.4
CUTOFF_POT: J6.11; also elsewhere on the board
DAC_PITCH: R60.1; also elsewhere on the board
DAC_PW: R28.1; also elsewhere on the board
DSQUARE: C3.2, J6.8; also elsewhere on the board
FM_IN: C3.1, J6.10; also elsewhere on the board
FM_OUT: J6.15, R24.1
GND: C17.2, C30.2, IC7.3 (+IN), IC7.5 (+IN), IC9.5 (+IN), IC10.3 (+IN), IC10.10 (+IN), IC10.12 (+IN), J3.S, J3.SN, J3.TN, J6.14, R64.1; also elsewhere on the board
MIX: IC10.14 (OUT), R31.2; also elsewhere on the board
MIX_SAW: J6.3, R33.1, R39.2
MIX_SQUARE: J6.5, R32.1, R38.2
unnamed: IC6.11 (CTRL), IC7.1 (OUT), R75.1 (E), R75.2 (S)
unnamed: C20.2, IC8.7 (OUT), R6.1, R27.1
unnamed: R61.2, R75.3 (A)
unnamed: Q1.1 (G), R6.2
unnamed: J3.T, R35.1
unnamed: R59.1, R74.1 (E), R74.2 (S)
unnamed: C9.1, IC6.12 (OUT), IC7.6 (-IN), Q1.2 (S)
unnamed: C32.1, IC8.3 (-IN), R63.1, R64.2
unnamed: IC6.6 (CTRL), R56.2
unnamed: IC9.6 (-IN), R28.2, R29.1, R30.2
unnamed: IC6.7 (IN), R57.2, R58.2, R59.2, R60.2
unnamed: C30.1, R57.1
unnamed: IC6.5 (OUT), IC7.2 (-IN), R61.1
unnamed: IC6.10 (IN), R22.2, R23.2, R24.2
unnamed: C17.1, R22.1
unnamed: IC9.7 (OUT), IC10.6 (-IN), R29.2
unnamed: IC10.2 (-IN), R70.2, R71.2, R72.1
unnamed: C20.1, IC8.2 (+IN), R26.2
unnamed: IC10.5 (+IN), R73.2
unnamed: IC10.9 (-IN), R36.2, R37.1, R40.2
unnamed: IC10.13 (-IN), R31.1, R32.2, R33.2, R34.2, R35.2
PW_POT: J6.7, R30.1
REF_4.096_TC: R56.1; also elsewhere on the board
REF_-4.096: R74.3 (A); also elsewhere on the board
SAW_INV: IC10.1 (OUT), IC11.1 (CLK), R39.1, R72.2, R73.1
SQUARE: IC10.7 (OUT), R38.1, R40.1
SUB: J6.1, R34.1
VCC: IC8.5 (ON), IC8.6 (ON/STR), IC8.8 (V+), J6.16, R27.2, R63.2; also elsewhere on the board
VCF_CV_IN: J6.9; also elsewhere on the board
VCO_CV_IN: J6.6, R58.1
VCO_RAMP: C9.2, C9.3, Q1.3 (D), R25.2
VCO_SAW_CORE: IC7.7 (OUT), R25.1, R26.1, R70.1
VCO_SYNC: C32.2, J6.13
VCO_TUNING_FB: IC10.8 (OUT), R37.2; also elsewhere on the board
VEE: IC8.1 (GND), IC8.4 (V-), IC11.2 (RES), J6.12, R23.1, R36.1, R71.1; also elsewhere on the board

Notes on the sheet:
cc-by-sa
Olivier Gillet
ol.gillet@gmail.com
VCO, mixer
or 40.2k
J112 or BF245B backwards
used under license
Niklas Andersson
signal@skookumsynth.com

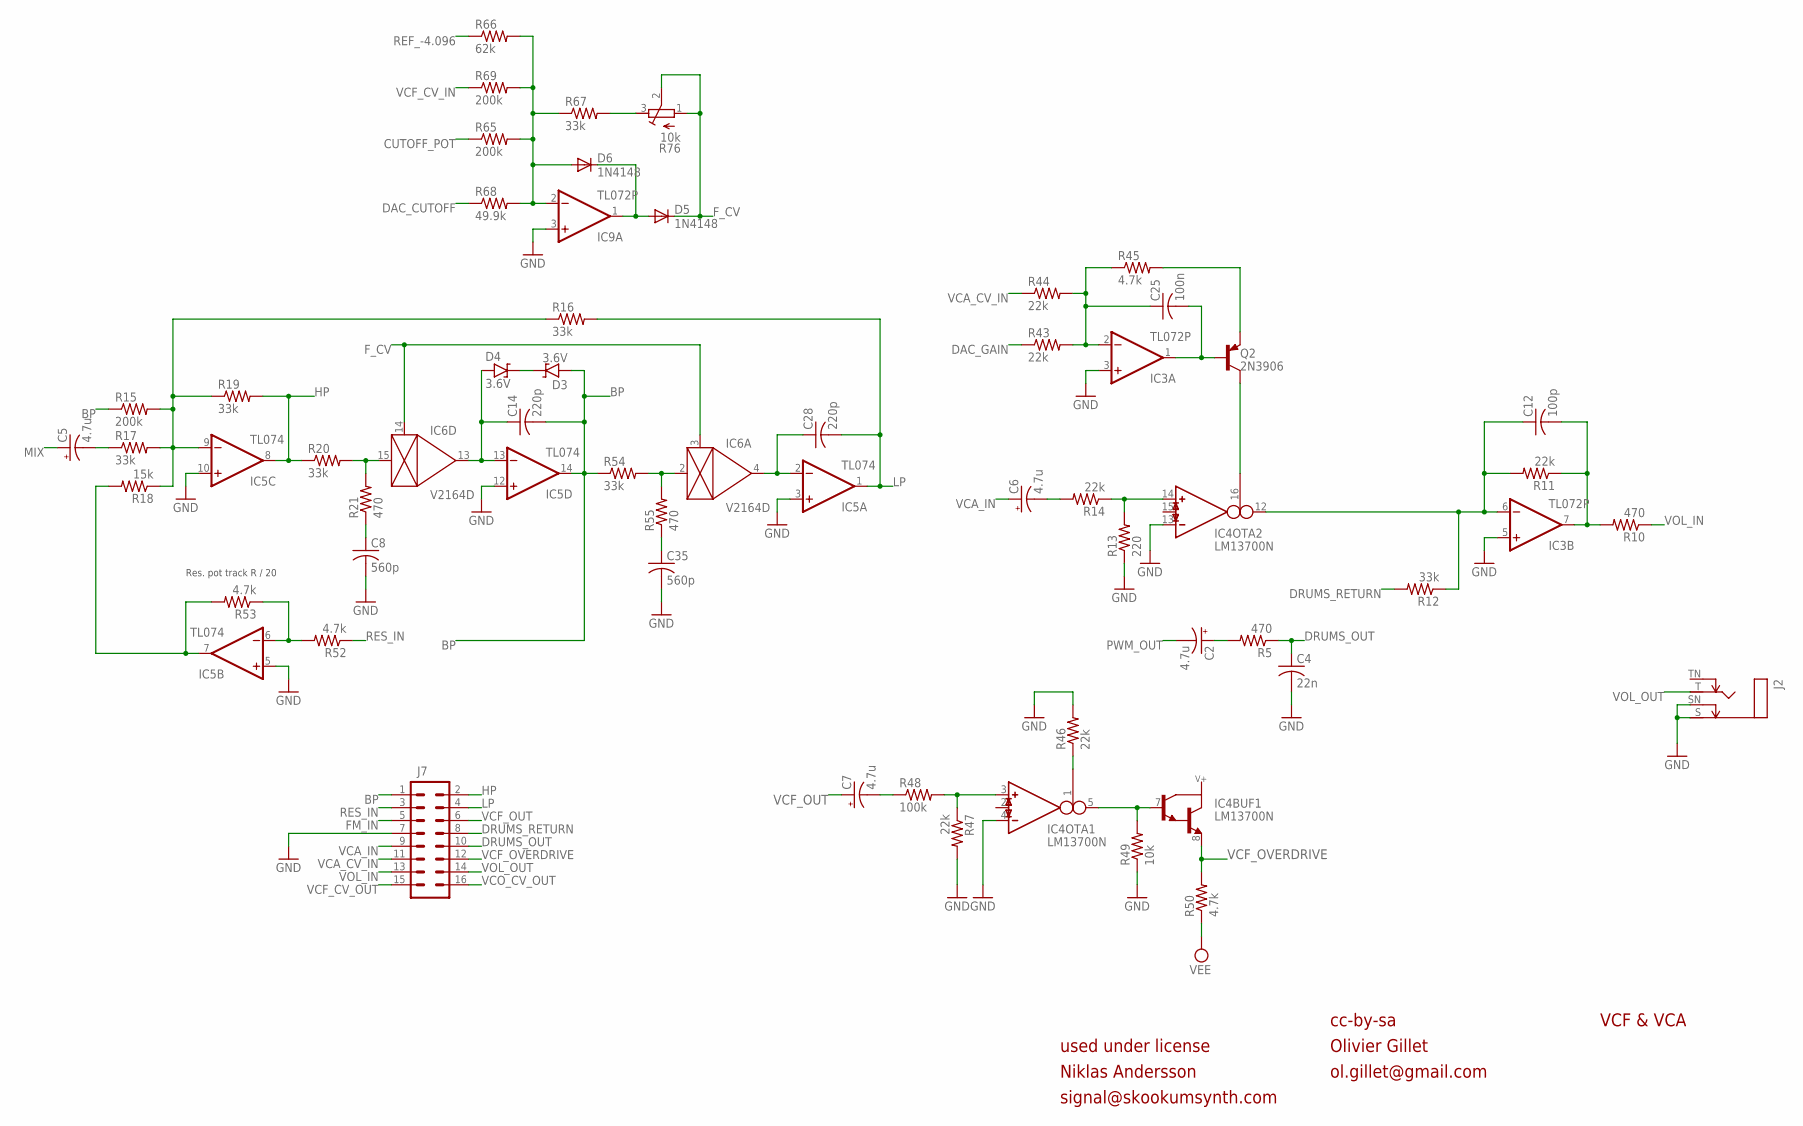
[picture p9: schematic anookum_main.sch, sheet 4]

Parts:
C2, C5, C6, C7: 4.7u; E2,5-6
C4: 22n; C050-030X075
C8, C35: 560p; C025-025X050
C12: 100p; C025-025X050
C14, C28: 220p; C025-025X050
C25: 100n; C025-025X050
D3, D4: 3.6V; D-5
D5, D6: 1N4148; D-5
IC3, IC9: TL072P; DIL08
IC4: LM13700N; DIL16
IC5: TL074; DIL14
IC6: V2164D; DIL16
J2: MONOSWSLIM; NRJ4HF
J7: M08X2; 2X8
Q2: 2N3906; TO92-
R5, R10, R21, R55: 470; 0204/7
R11, R14, R43, R44, R46, R47: 22k; 0204/7
R12, R16, R17, R19, R20, R54, R67: 33k; 0204/7
R13: 220; 0204/7
R15, R65, R69: 200k; 0204/7
R18: 15k; 0204/7
R45, R50, R52, R53: 4.7k; 0204/7
R48: 100k; 0204/7
R49: 10k; 0204/7
R66: 62k; 0204/7
R68: 49.9k; 0204/7
R76: 10k; RTRIM3296W

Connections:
BP: C14.2, D3.A, IC5.14 (OUT), J7.1, R15.1, R54.1
CUTOFF_POT: R65.1; also elsewhere on the board
DAC_CUTOFF: R68.1; also elsewhere on the board
DAC_GAIN: R43.1; also elsewhere on the board
DRUMS_OUT: C4.1, J7.10, R5.1
DRUMS_RETURN: J7.8, R12.2
FM_IN: J7.5; also elsewhere on the board
F_CV: D5.C, IC6.3 (CTRL), IC6.14 (CTRL), R76.1 (E), R76.2 (S)
GND: C4.2, C8.2, C35.2, IC3.3 (+IN), IC3.5 (+IN), IC4.4 (IN_N), IC4.13 (IN_N), IC5.3 (+IN), IC5.5 (+IN), IC5.10 (+IN), IC5.12 (+IN), IC9.3 (+IN), J2.S, J2.SN, J7.7, R13.1, R46.2, R47.2, R49.1; also elsewhere on the board
HP: IC5.8 (OUT), J7.2, R19.2, R20.1
LP: C28.2, IC5.1 (OUT), J7.4, R16.2
MIX: C5.+; also elsewhere on the board
unnamed: C2.+, R5.2
unnamed: IC5.9 (-IN), R15.2, R16.1, R17.2, R18.1, R19.1
unnamed: C28.1, IC5.2 (-IN), IC6.4 (OUT)
unnamed: C8.1, R21.1
unnamed: IC5.6 (-IN), R52.2, R53.1
unnamed: IC5.7 (OUT), R18.2, R53.2
unnamed: C5.-, R17.1
unnamed: C35.1, R55.1
unnamed: C14.1, D4.A, IC5.13 (-IN), IC6.13 (OUT)
unnamed: R67.2, R76.3 (A)
unnamed: IC4.16 (I_BIAS), Q2.1 (C)
unnamed: IC6.2 (IN), R54.2, R55.2
unnamed: C7.-, R48.1
unnamed: IC6.15 (IN), R20.2, R21.2
unnamed: C6.-, R14.2
unnamed: D5.A, D6.C, IC9.1 (OUT)
unnamed: Q2.3 (E), R45.2
unnamed: D6.A, IC9.2 (-IN), R65.2, R66.2, R67.1, R68.2, R69.2
unnamed: C25.2, IC3.1 (OUT), Q2.2 (B)
unnamed: IC4.14 (IN_P), R13.2, R14.1
unnamed: D3.C, D4.C
unnamed: C12.2, IC3.7 (OUT), R10.2, R11.1
unnamed: C12.1, IC3.6 (-IN), IC4.12 (OUT), R11.2, R12.1
unnamed: IC4.1 (I_BIAS), R46.1
unnamed: IC4.3 (IN_P), R47.1, R48.2
unnamed: IC4.5 (OUT), IC4.7 (B), R49.2
unnamed: C25.1, IC3.2 (-IN), R43.2, R44.2, R45.1
PWM_OUT: C2.-; also elsewhere on the board
REF_-4.096: R66.1; also elsewhere on the board
RES_IN: J7.3, R52.1
VCA_CV_IN: J7.11, R44.1
VCA_IN: C6.+, J7.9
VCF_CV_IN: R69.1; also elsewhere on the board
VCF_CV_OUT: J7.15; also elsewhere on the board
VCF_OUT: C7.+, J7.6
VCF_OVERDRIVE: IC4.8 (E), J7.12, R50.2
VCO_CV_OUT: J7.16; also elsewhere on the board
VEE: R50.1; also elsewhere on the board
VOL_IN: J7.13, R10.1
VOL_OUT: J2.T, J7.14

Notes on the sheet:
Res. pot track R / 20
cc-by-sa
Olivier Gillet
ol.gillet@gmail.com
VCF & VCA
used under license
Niklas Andersson
signal@skookumsynth.com

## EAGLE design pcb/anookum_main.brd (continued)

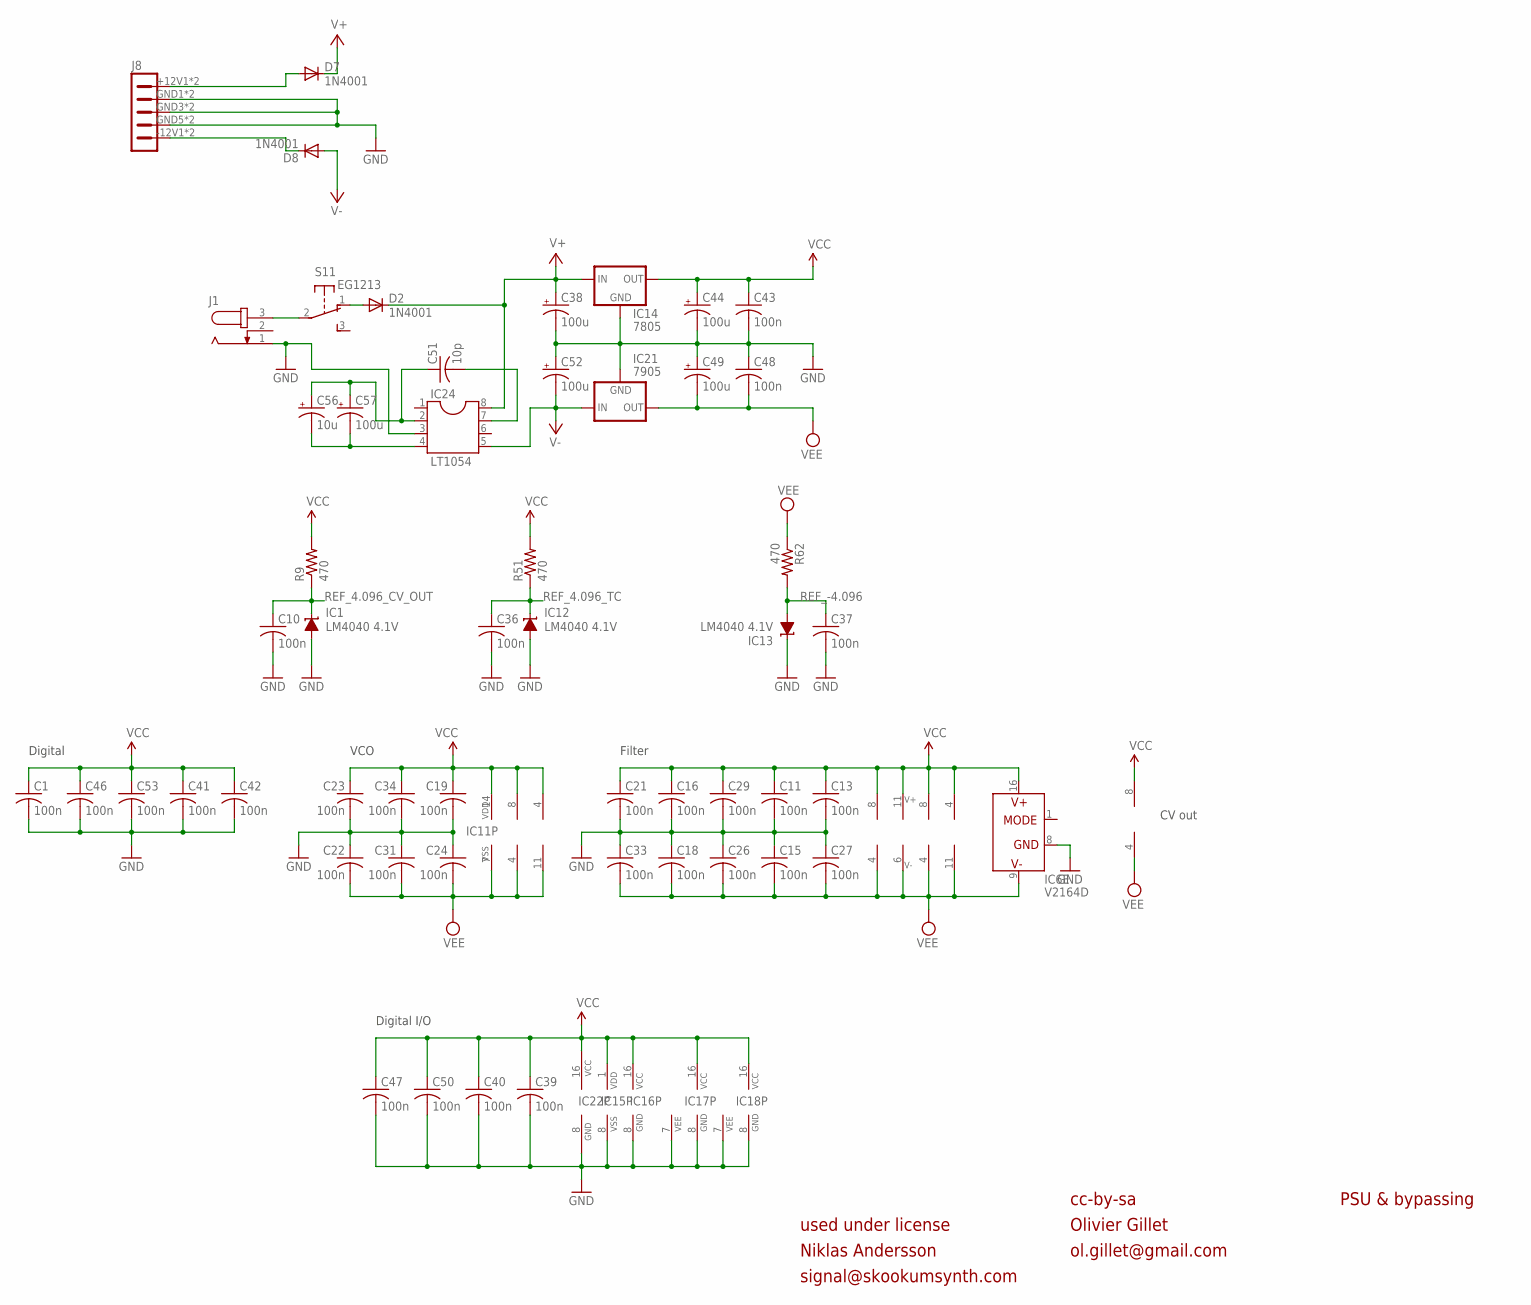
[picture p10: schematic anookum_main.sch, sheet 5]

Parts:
C1, C10, C11, C13, C15, C16, C18, C19, C21, C22, C23, C24, C26, C27, C29, C31, C33, C34, C36, C37, C39, C40, C41, C42, C43, C46, C47, C48, C50, C53: 100n; C025-025X050
C38, C44, C49, C52: 100u; E2,5-7
C51: 10p; C025-025X050
C56: 10u; E2,5-5
C57: 100u; E2,5-6
D2, D7, D8: 1N4001; DO41-10
IC1, IC12, IC13: LM4040 4.1V; LP_O-PBCY-W3
IC2: TS912; DIL08
IC3, IC7, IC9: TL072P; DIL08
IC4: LM13700N; DIL16
IC5, IC10: TL074; DIL14
IC6: V2164D; DIL16
IC11: 4024N; DIL14
IC14: 7805; 78XXS
IC15: 4050N; DIL16
IC16: 74HC595N; DIL16
IC17, IC18: 4051N; DIL16
IC21: 7905; 79XXS
IC22: 74HC165N; DIL16
IC24: LT1054; DIL08
J1: JACK-PLUG2; SPC4078_BIG_HOLES
J8: HDR_POWER_10_VERT; HDR_POWER_10
R9, R51, R62: 470; 0204/7
S1: EG1213

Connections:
GND: C1.2, C10.2, C11.2, C13.2, C15.1, C16.2, C18.1, C19.2, C21.2, C22.1, C23.2, C24.1, C26.1, C27.1, C29.2, C31.1, C33.1, C34.2, C36.2, C37.2, C38.-, C39.2, C40.2, C41.2, C42.2, C43.2, C44.-, C46.2, C47.2, C48.1, C49.+, C50.2, C52.+, C53.2, IC1.3 (A), IC6.8 (GND), IC12.3 (A), IC13.2 (C), IC14.GND, IC15.8 (VSS), IC16.8 (GND), IC17.7 (VEE), IC17.8 (GND), IC18.7 (VEE), IC18.8 (GND), IC21.GND, IC22.8 (GND), IC24.3, J1.1, J8.GND1 (2), J8.GND2 (2), J8.GND3 (3), J8.GND4 (3), J8.GND5 (4), J8.GND6 (4); also elsewhere on the board
unnamed: J1.3, S1.2
unnamed: D2.A, S1.1 (O)
unnamed: C51.1, C56.+, C57.+, IC24.2
unnamed: D7.A, J8.+12V1 (1), J8.+12V2 (1)
unnamed: D8.C, J8.-12V1 (5), J8.-12V2 (5)
unnamed: C56.-, C57.-, IC24.4
unnamed: C51.2, IC24.7
REF_4.096_CV_OUT: C10.1, IC1.2 (C), R9.1; also elsewhere on the board
REF_4.096_TC: C36.1, IC12.2 (C), R51.1; also elsewhere on the board
REF_-4.096: C37.1, IC13.3 (A), R62.2; also elsewhere on the board
V+: C38.+, D2.C, D7.C, IC14.IN, IC24.8
V-: C52.-, D8.A, IC21.IN, IC24.5
VCC: C1.1, C11.1, C13.1, C16.1, C19.1, C21.1, C23.1, C29.1, C34.1, C39.1, C40.1, C41.1, C42.1, C43.1, C44.+, C46.1, C47.1, C50.1, C53.1, IC2.8 (V+), IC3.8 (V+), IC4.11 (V+), IC5.4 (V+), IC6.16 (V+), IC7.8 (V+), IC9.8 (V+), IC10.4 (V+), IC11.14 (VDD), IC14.OUT, IC15.1 (VDD), IC16.16 (VCC), IC17.16 (VCC), IC18.16 (VCC), IC22.16 (VCC), R9.2, R51.2; also elsewhere on the board
VEE: C15.2, C18.2, C22.2, C24.2, C26.2, C27.2, C31.2, C33.2, C48.2, C49.-, IC2.4 (V-), IC3.4 (V-), IC4.6 (V-), IC5.11 (V-), IC6.9 (V-), IC7.4 (V-), IC9.4 (V-), IC10.11 (V-), IC11.7 (VSS), IC21.OUT, R62.1; also elsewhere on the board

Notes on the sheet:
Digital
VCO
Filter
CV out
cc-by-sa
Olivier Gillet
ol.gillet@gmail.com
PSU & bypassing
Digital I/O
used under license
Niklas Andersson
signal@skookumsynth.com

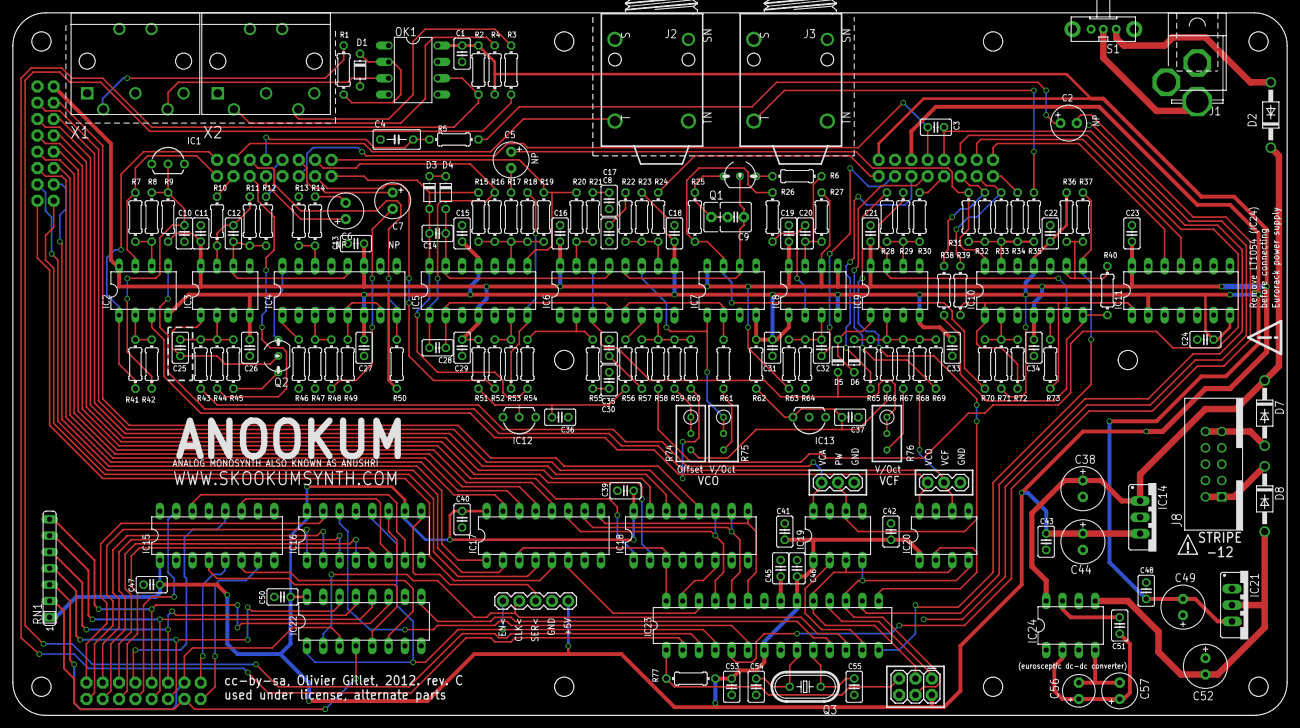
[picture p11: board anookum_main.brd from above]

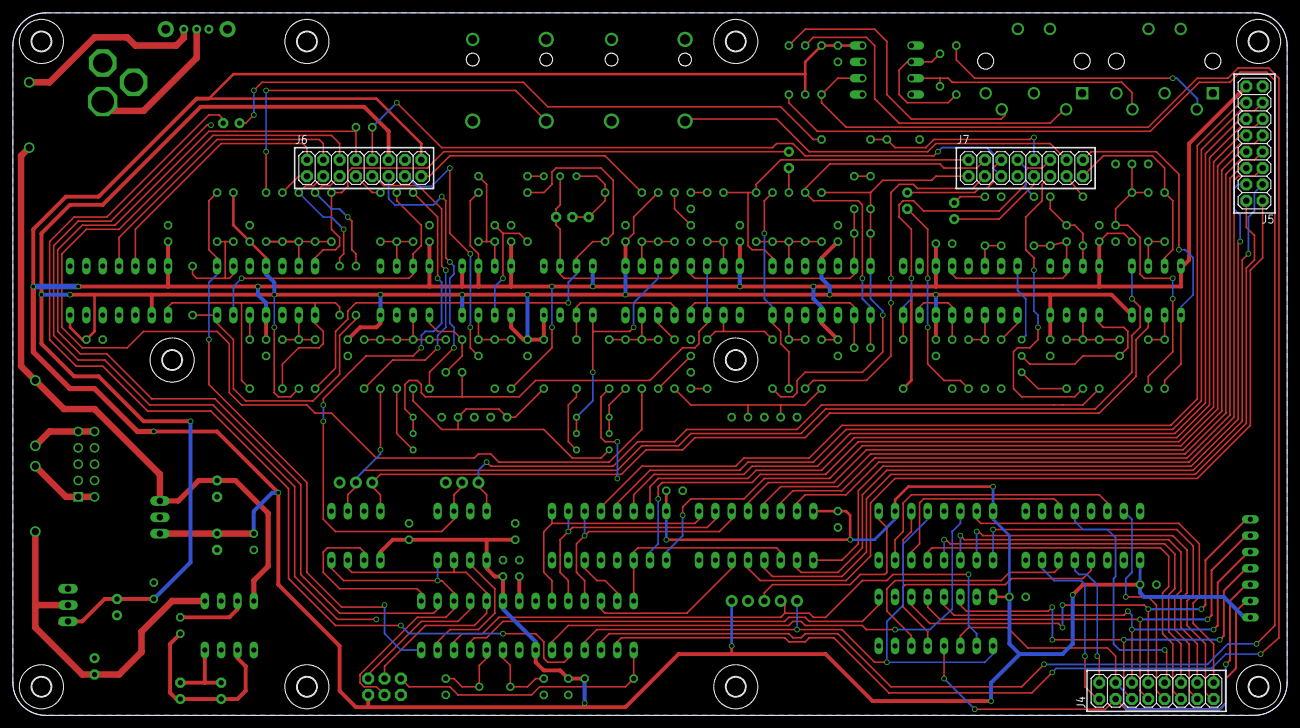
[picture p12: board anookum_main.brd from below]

Board: 2 copper layers, 198.1 x 109.2 mm, 196 parts (14 on the bottom side), 165 nets.

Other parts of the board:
U$3, U$4, U$5, U$6, U$7, U$8, U$9, U$10, U$11, U$12: 3,0

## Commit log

2016-06-04 new bom
    [anookum_bom.xlsx, anookum_panel.dwg, anu.dwg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]
2016-06-09 Revised
    10kA ->100kA
    [anookum_bom.xlsx]

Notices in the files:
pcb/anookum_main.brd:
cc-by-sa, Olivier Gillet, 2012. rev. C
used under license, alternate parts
